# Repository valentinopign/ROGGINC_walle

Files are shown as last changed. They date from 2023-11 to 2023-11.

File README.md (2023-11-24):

# ROGGINC_walle
Proyecto final que encabezamos durante nuestra estadia en 7mo año para la materia de "Proyecto y diseño electronico"
Imagen de WhatsApp 2023-11-24 a las 00 20 57_812ecb64

Inspirados por la icónica película de Disney, tomamos la decisión
de modelar nuestro proyecto tomando la forma del entrañable
personaje principal, Wall-E. Este robot carismático se ha
convertido en un ícono, y decidimos emular su diseño distintivo
para crear un dispositivo interactivo y encantador.
Para lograr este objetivo, optamos por utilizar la tecnología de
impresión 3D para recrear no solo la forma general de Wall-E,
sino también sus característicos engranajes, añadiendo
autenticidad y detalle a nuestro proyecto. La impresión 3D nos
proporcionó la flexibilidad necesaria para capturar la esencia del
personaje de manera precisa y personalizada.
El enfoque principal de nuestro proyecto fue desarrollar un robot
capaz de moverse e interactuar de manera amigable con las
personas, y la elección de Wall-E como inspiración nos
proporcionó una base sólida para lograr este objetivo. Su diseño
único y su personalidad afectuosa sirvieron como punto de
partida para crear un dispositivo que no solo fuera funcional, sino
también emocionalmente atractivo.

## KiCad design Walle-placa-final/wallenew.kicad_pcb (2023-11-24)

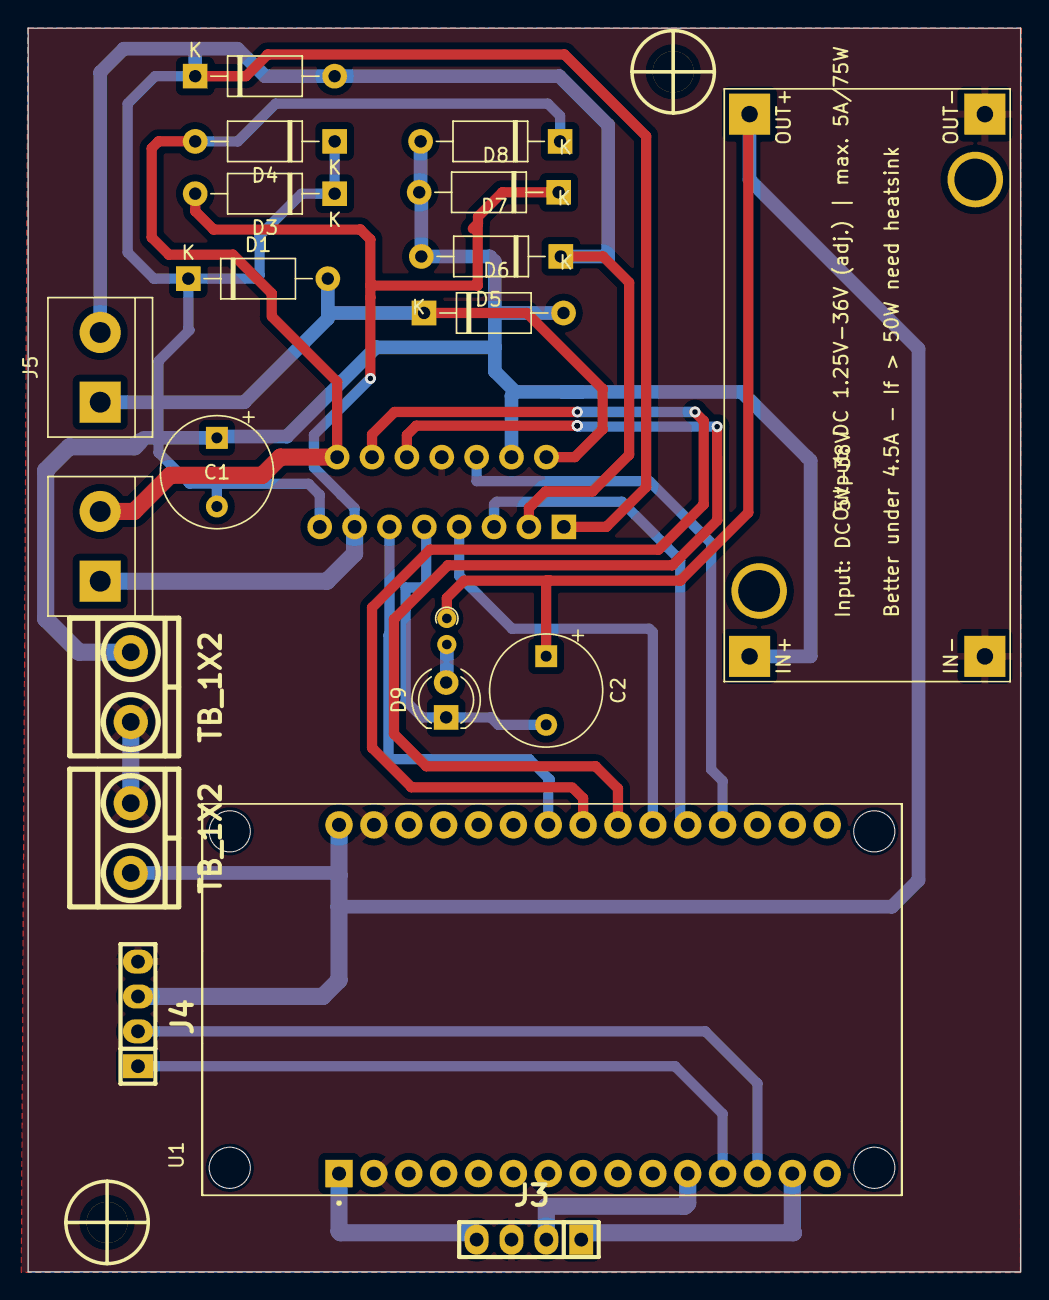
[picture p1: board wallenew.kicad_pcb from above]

Board: 2 copper layers, 72.3 x 90.6 mm, 23 parts (1 on the bottom side), 17 nets.

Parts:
C1, C2: 220uF; CP_Radial_Tantal_D8.0mm_P5.00mm
D1, D2, D3, D4, D5, D6, D7, D8: DIODE; D_A-405_P10.16mm_Horizontal
D9: LED; LED_D4.0mm
H1, H2: Mounting_Hole; hole_3mm
J1, J2: TB_1X2; BORNERA2_AZUL
J3, J4: Conn_01x04; pin_strip_4
J5, J6: TB_1X2; TerminalBlock_bornier-2_P5.08mm
PS1: XL4005_DC-DC
R1: R; R_Axial_DIN0204_L3.6mm_D1.6mm_P1.90mm_Vertical
U1: ESP32-DEVKIT-V1; MODULE_ESP32_DEVKIT_V1
U2: L298N; TO-220-15_P2.54x2.54mm_StaggerOdd_Lead4.58mm_Vertical

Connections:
5V: C2.1, J1.1, J4.3, PS1.3 (OUT+), R1.1, U1.30 (VIN)
/3.3V: J3.4, U1.1 (3V3)
/PWM1: U1.19 (D34), U2.6 (EnA)
/PWM2: U1.24 (D26), U2.11 (EnB)
/RX: J4.2, U1.13 (TX0)
/SCL: J3.1, U1.14 (D22)
/SDA: J3.2, U1.11 (D21)
/TX: J4.1, U1.12 (RX0)
/in1: U1.20 (D35), U2.5 (IN1)
/in2: U1.21 (D32), U2.7 (IN2)
/in3: U1.22 (D33), U2.10 (IN3)
/in4: U1.23 (D25), U2.12 (IN4)
GND: J1.2, J2.1, J3.3, J4.4, PS1.2 (IN-), PS1.4 (OUT-), U1.2 (GND), U1.29 (GND), U2.8 (GND)
unnamed: C1.1, C1.2, D1.1 (A), D1.2 (K), D2.1 (A), D2.2 (K), D3.1 (A), D4.1 (A), D4.2 (K), D5.1 (A), D5.2 (K), D6.1 (A), D6.2 (K), D7.2 (K), D8.1 (A), D8.2 (K), J2.2, J5.1, J5.2, J6.2, PS1.1 (IN+), U2.1 (SENSE_A), U2.2 (OUT1), U2.3 (OUT2), U2.4 (Vs), U2.14 (OUT4), U2.15 (SENSE_B)
unnamed: D3.2 (K), D7.1 (A), J6.1, U2.13 (OUT3)
unnamed: D9.2 (A), R1.2
unnamed: C2.2, D9.1 (K), U2.9 (Vss)

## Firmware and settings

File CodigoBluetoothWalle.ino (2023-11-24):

#define RIGHT 18 
#define RIGHT2 23 


#define LEFT 19  
#define LEFT2 4 


#include <Wire.h>
#include <Adafruit_PWMServoDriver.h>
Adafruit_PWMServoDriver pca9685;

#include "BluetoothSerial.h"
BluetoothSerial BT;

#define SERVO1_PIN_L 0 // Canal del PCA9685 para el primer servo
#define SERVO2_PIN_R 1
#define SERVO3_PIN_H 2
#define SERVO4_PIN_N 3



int grad = 0;


void Stop();
void forward();
void back();
void left();
void right();
void topright();
void topleft();
void bottomright();
void bottomleft();

#define SERVOMIN 150 // This is the 'minimum' pulse length count (out of 4096)
#define SERVOMAX 220 // ) //cambiar / subir para dejar al servo moverse mas //o puede ser USMAX
#define USMIN 150 // This is the rounded 'minimum' microsecond length based on the minimum pulse of 150
#define USMAX 600 // This is the rounded 'maximum' microsecond length based on the maximum pulse of 600
#define SERVO_FREQ 50 // Analog servos run at ~50 Hz updates


void setup(){
  
  
    pinMode(RIGHT, OUTPUT);
    pinMode(RIGHT2, OUTPUT);
    pinMode(LEFT, OUTPUT);
    pinMode(LEFT2, OUTPUT);


    pca9685.begin();
    pca9685.setOscillatorFrequency(27000000);
    pca9685.setPWMFreq(SERVO_FREQ); // Analog servos run at ~50 Hz updates; // Establecer la frecuencia PWM en 60 Hz

    // Configura la posición inicial de los servos
    pca9685.setPWM(SERVO1_PIN_L, 0, 4095); // Coloca el servo 1 en la posición inicial
    pca9685.setPWM(SERVO2_PIN_R, 0, 4095);
    
    Serial.begin(115200);
    BT.begin("rodvert");
}


void loop(){
  if (BT.available()) {
    int read = BT.read();
    //while 
   
     listenBluetoothCommands(read);
      listenServosCommands(read);
  }else{
    Stop();
  }
  delay(10);
}

void listenBluetoothCommands(int val){
  if (val == 'F'){
    forward();
    Serial.println("F");
  }

  if (val == 'G'){
    back();
    Serial.println("G");

  }

  if (val == 'L'){
    left();
    Serial.println("L");
  }

  if (val == 'R'){
    Serial.println("R");
      right();
  }
  if (val == 'Q'){
    Serial.println("Q");
   topright();
  }

  if (val == 'E'){
    Serial.println("E");

    topleft();
  }

  if (val == 'Z'){
    Serial.println("Z");
    bottomright();
  }

  if (val == 'C'){
    Serial.println("C");
    bottomleft();
  }

  if (val == 'S'){ //sin comillas
    Stop(); 
  }
}
  

void listenServosCommands(int val){
  Serial.println("Val is");
  Serial.println(val);
  
  if (val == 89){ 
      while(true){ //dangereous
        Serial.println("up & down left");
        for (int i = 0; i < 270;i++){
          moveServo(SERVO1_PIN_L,i);
          delay(10);
          Serial.println("up");
        }
        delay(1000);
        for (int i = 270; i >= 0;i--){
          moveServo(SERVO1_PIN_L,i);
          delay(10);
          Serial.println(" downt");
        }
        Serial.println("finish down and up ");
        break;
      }
    }
      if (val == 88){ //change later
      while(true){ //dangereous
        Serial.println("up & down left");
        for (int i = 0; i < 180;i++){
          moveServo(SERVO2_PIN_R,i);
          delay(10);
          Serial.println("up");
        }
        delay(1000);
        for (int i = 180; i >= 0;i--){
          moveServo(SERVO2_PIN_R,i);
          delay(10);
          Serial.println(" downt");
        }
        Serial.println("finish down up :v uwu");
        break;
      }
    }
      if (val == 77){ //CUELLITOp
      while(true){ //dangereous
        Serial.println("up and down neckbottom");
        for (int i = 0; i < 360;i++){
          moveServo(SERVO3_PIN_H,i);
          delay(10);
          Serial.println("upp");
        }
        delay(1000);
        for (int i = 360; i >= 0;i--){
          moveServo(SERVO3_PIN_H,i);
          delay(10);
          Serial.println(" downtt");
        }
        Serial.println("finish down up :v uwu");
        break;
      }
    }
      if (val == 78){ //CABEZA
      while(true){ //dangereous
        Serial.println("up & down necktop");
        for (int i = 0; i < 400;i++){
          moveServo(SERVO4_PIN_N,i);
          delay(10);
          Serial.println("upi");
        }
        delay(1000);
        for (int i = 400; i >= 0;i--){
          moveServo(SERVO4_PIN_N,i);
          delay(10);
          Serial.println(" downti");
        }
        Serial.println("finish down up :v uwu");
        break;
      }
    }
    
}

void moveServo(uint8_t servoPin, int degrees) {
  uint8_t pulselength = map(degrees, 0, 180, SERVOMIN, SERVOMAX);
  pca9685.setPWM(servoPin, 0, pulselength); // Establecer la posición del servo
}

void forward()
{
 digitalWrite(RIGHT, HIGH);
  digitalWrite(RIGHT2, LOW);
 

  digitalWrite(LEFT, HIGH);
  digitalWrite(LEFT2, LOW);
  
}
   
void back()
{
  digitalWrite(RIGHT, LOW);
  digitalWrite(RIGHT2, HIGH);
  

  digitalWrite(LEFT, LOW);
  digitalWrite(LEFT2, HIGH);
  
}
   
void left()
{
 
  digitalWrite(RIGHT, HIGH);
  digitalWrite(RIGHT2, LOW);
  

  digitalWrite(LEFT, LOW);
  digitalWrite(LEFT2, HIGH);
  
 
   
}
   
void right()
{
 
  digitalWrite(RIGHT, LOW);
  digitalWrite(RIGHT2, HIGH);
 

  digitalWrite(LEFT, HIGH);
  digitalWrite(LEFT2, LOW);
  
   
}
   
void topleft(){
 
    digitalWrite(RIGHT, HIGH);
  digitalWrite(RIGHT2, LOW);
 

  digitalWrite(LEFT, LOW);
  digitalWrite(LEFT2, LOW);
  
 
}
   
void topright()
{
  
    digitalWrite(RIGHT, LOW);
  digitalWrite(RIGHT2, LOW);
 

  digitalWrite(LEFT, HIGH);
  digitalWrite(LEFT2, LOW);
  

 

   
}
   
void bottomleft()
{
 
  digitalWrite(RIGHT, LOW);
  digitalWrite(RIGHT2, LOW);
  

  digitalWrite(LEFT, LOW);
  digitalWrite(LEFT2, HIGH);
  

 
   
}
   
void bottomright()
{
 
 
 
  digitalWrite(RIGHT, LOW);
  digitalWrite(RIGHT2, HIGH);
 

  digitalWrite(LEFT, LOW);
  digitalWrite(LEFT2, LOW);
  
   
 
}
   
   
void Stop()
{
  digitalWrite(RIGHT, LOW);
  digitalWrite(RIGHT2, LOW);
 

  digitalWrite(LEFT, LOW);
  digitalWrite(LEFT2, LOW);
  
}
